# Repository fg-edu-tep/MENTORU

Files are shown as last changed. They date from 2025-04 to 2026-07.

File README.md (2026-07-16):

# MENTORU

Sistema de monitoreo biométrico distribuido basado en ESP32. Varios dispositivos vestibles (reloj, gafas, pecho, sensor GSR) miden señales fisiológicas y de movimiento, y las transmiten de forma inalámbrica por **ESP-NOW** a un receptor central que las expone como JSON vía HTTP.

Proyecto de la asignatura *Fundamentos de Electrónica* (Universidad de los Andes).

## Arquitectura

Cada dispositivo sensor transmite tramas de tamaño fijo (88 bytes) usando el protocolo propio **ESB-P** (*ESP-NOW Sensor Broadcast Protocol*, ver [`ESB-P_ESP-NOW SENSOR BROADCAST PROTOCOL DRAFT 1.pdf`](<./ESB-P_  ESP-NOW SENSOR BROADCAST PROTOCOL           DRAFT 1.pdf>)). Cada trama tiene:

```c
typedef struct __attribute__((packed)) {
  char    deviceId[16];      // identifica el dispositivo
  char    broadcastType[16]; // tipo de dato: FORM, HR, VMEDIDO, ACCEL, FLEX...
  uint8_t payload[56];       // datos específicos de cada tipo
} espMessage;
```

Un único receptor ESP32 escucha todas las tramas, agrupa por `deviceId` + `broadcastType`, y sirve el último valor de cada uno en `GET /devices` como JSON.

## Dispositivos

| Carpeta | Dispositivo | Descripción |
|---|---|---|
| [`MasterReciever/`](MasterReciever) | Receptor | Proyecto PlatformIO (ESP32-S3). SoftAP + ESP-NOW, sirve `/devices`. Incluye además un sensor "Vest" propio a bordo (MPU-6050 + flex) que se muestrea localmente. |
| [`Wk/`](Wk) | Reloj | Pantalla LCD redonda + touch (CST816S) + sensor de ritmo cardíaco MAX30102, interfaz LVGL con asistente de formulario. Transmite `FORM` y `HR`. |
| [`Arduino/GSR/`](Arduino/GSR) | Sensor GSR | Lee la respuesta galvánica de la piel por ADC y transmite `VMEDIDO`. |
| [`GSR sensor/`](GSR%20sensor) | Sensor GSR (PCB) | Diseño KiCad del PCB del sensor GSR, con archivos de fabricación (gerbers). |
| [`PCB_Gafas/`](PCB_Gafas) | Gafas | Diseño KiCad del PCB del dispositivo de gafas (acelerómetro, `ACCEL`). |
| [`PCB_Pecho/`](PCB_Pecho) | Pecho | Diseño KiCad del PCB del dispositivo de pecho (acelerómetro + flex, `ACCEL`/`FLEX`). |
| [`Fuente Fundamentos/`](<Fuente Fundamentos>) · [`PCB_Fuente/`](PCB_Fuente) | Fuente de alimentación | Diseño de la fuente/boost converter (Altium y KiCad respectivamente). |
| [`Arduino/ESP32RECEPTORA/`](Arduino/ESP32RECEPTORA) | Receptor (versión anterior) | Primera versión del receptor, solo maneja Reloj (`FORM`/`HR`) y GSR (`VMEDIDO`). Reemplazada por `MasterReciever/`. |

## Hardware / PCBs (KiCad)

`KiCad_FootPrints/` contiene las librerías de footprints y símbolos usadas por los diseños anteriores:

- `usini_kicad_sensors-main/` — librería de sensores I2C de terceros (ADXL345, BMP180, MPL3115A2, PAJ7620, SI7021, TSL2561, INA219, BH1750, BME280/680, MAX30102, MPU6050, VL53L0X, MLX90614, conector de audio TRRS).
- `XIAO_ESP32C3-main/` — símbolo/footprint del módulo Seeed XIAO ESP32C3.
- `ESP32-S3/`, `BoostConverter/`, `CostumFuse/`, `Transformer/` — footprints propios adicionales.

## Compilar y flashear

- **`MasterReciever/`** — proyecto PlatformIO, board `esp32-s3-devkitc-1`, framework Arduino. Compilar con `pio run` o desde la extensión de PlatformIO.
- **`Wk/`** (`Wk.ino`) y **`Arduino/*/`** — sketches de Arduino IDE, requieren el core de ESP32 y las librerías `lvgl`, `TFT_eSPI`, `MAX30105`/`heartRate`, `esp_now`.

## Documentación

- [`ESB-P_ESP-NOW SENSOR BROADCAST PROTOCOL DRAFT 1.pdf`](<./ESB-P_  ESP-NOW SENSOR BROADCAST PROTOCOL           DRAFT 1.pdf>) — especificación del protocolo de comunicación entre dispositivos y receptor.
- [`Informe_Final.pdf`](Informe_Final.pdf) — informe final del proyecto.

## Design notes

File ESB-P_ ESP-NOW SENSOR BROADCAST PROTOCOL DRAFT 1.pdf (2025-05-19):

ESB-P: ESP-NOW SENSOR BROADCAST PROTOCOL DRAFT 1.1 ----------------------------------------------------------------
Status : Experimental | Editors : Embedded Systems Team
Date : 2025-05-17 | Expires : 2026-05-17
0 Document Structure (Quick Guide for GPT Agents)
yaml
Copiar
Editar
§1 Introduction
§2 Conventions & Terminology
§3 Frame Format (generic, device-agnostic)
§4 Typical Frame Construction (step-by-step recipe) §5 Receiver Behaviour & /devices JSON schema §6 Project-Specific Frames
├─ 6.1 Reloj : FORM
├─ 6.2 Reloj : HR
├─ 6.3 GSR : VMEDIDO
├─ 6.4 Gafas : ACCEL
└─ 6.5 Pecho : ACCEL / FLEX
§7 Extensibility & Versioning
§8 Reference Source Code Pointers ┈┈┈┈┈┈┈┈┈┈┈┈┈┈┈┈┈┈┈┈┈┈┈┈┈┈┈┈┈┈┈┈┈

1 Introduction
ESB-P defines one fixed-length ESP-NOW frame that every ESP32-class Sensor Device broadcasts.
A single Receiver ESP32 listens, de-multiplexes by deviceId + broadcastType, and makes the latest values available via HTTP/JSON.

2 Conventions & Terminology
Term Meaning
deviceId | Null-terminated ASCII ≤ 15 chars identifying the board.
broadcastType | Null-terminated ASCII ≤ 15 chars describing the payload kind (“HR”,
“ACCEL”…).
frame Exactly 88 bytes transmitted with esp_now_send().
Sensor DeviceAny ESP32 that sends ESB-P frames.
Receiver The ESP32 that receives all ESB-P traffic and serves /devices JSON.

Channel: All nodes must share the same Wi-Fi channel (default 1).

3 Frame Format (generic)
c
Copiar

Editar
/* Total size: 88 bytes */
typedef struct __attribute__((packed)) {
char deviceId[16]; // §2
char broadcastType[16]; // §2
uint8_t payload[56]; // device-specific use
} espMessage;
Why 56 bytes? 16 + 16 + 56 = 88, which fits comfortably inside one ESP-NOW MAC payload (limit ≈ 250 B).

All devices send the same 88-byte struct – they just lay out the 56-byte payload differently.

4 Typical Frame Construction (Recipe)
Clear and identify

c
Copiar
Editar
espMessage msg = {}; | // zero-fill
strncpy(msg.deviceId, "MySensor01", 15); strncpy(msg.broadcastType, "TEMP", 15); Encode payload
Example: store a little-endian 32-bit float at byte 0.

c
Copiar
Editar
float T = 23.7f;
memcpy(&msg.payload[0], &T, sizeof(T)); // 4 bytes Send

c
Copiar
Editar
const uint8_t bc[6] = {0xFF,0xFF,0xFF,0xFF,0xFF,0xFF};
esp_now_send(bc, (uint8_t*)&msg, sizeof(msg));
5 Receiver Behaviour & JSON Schema
Mode: WIFI_AP_STA ➜ SoftAP “ESP_Receiver” (channel 1) plus ESP-NOW STA. Callback: On every frame, group by deviceId, then by broadcastType,
store the latest payload.

5.1 /devices Response
json

Copiar
Editar
{
"devices":[
{
"id":"Clock",
"FORM": { "edad":"25","altura":"170","peso":"70", ... }, "HR" : 72,
"ACCEL": { "ax":-12,"ay":34,"az":1000 }
},
{
"id":"GSR",
"VMEDIDO": 0.523
}
]
}
Rules

Every top-level object == one unique deviceId.

Keys inside are broadcastType values.

Receiver may attach timestamps or extra meta-fields in future.

6 Project-Specific Frames
6.1 Reloj → “FORM”
Field Offset Bytes Encoding | Example
edad 0 | 4 | ASCII "25"
altura 4 | 4 | ASCII "170"
peso 8 | 4 | ASCII "70"
vasos 12 | 4 | ASCII " 8"
hrs | 16 | 4 | ASCII " 7"
nivel 20 | 16 | ASCII "Moderado"
padding | 36 | 20 | zero n/a

6.2 Reloj → “HR”
less
Copiar
Editar
payload[0..3] : int32 little-endian (beats per minute) payload[4..55]: zero padding
6.3 GSR → “VMEDIDO”
less
Copiar

Editar
payload[0..3] : 32-bit float (skin voltage, volts) payload[4..55]: padding
6.4 Gafas → “ACCEL”
less
Copiar
Editar
payload[0..1] : int16 ax
payload[2..3] : int16 ay
payload[4..5] : int16 az
payload[6..55]: padding
6.5 Pecho → “ACCEL” & “FLEX”
ACCEL = same layout as 6.4.

FLEX : payload[0..1] = uint16 resistance (Ω); rest padding.

A device may broadcast multiple broadcastTypes back-to-back.

7 Extensibility & Versioning
A new sensor only needs to pick:

ini
Copiar
Editar
deviceId = "YourBoardName"
broadcastType = "NEWTYPE"
payload = your ≤56-byte layout
Receiver must add a case for "NEWTYPE" if it wants to parse it; otherwise it can store the raw 56-byte blob.

Future protocol versions may add uint8_t version as the first byte of the frame; receivers should ignore unknown versions safely.

8 Reference Source Code
Component | File | Notes
Clock (form + HR) | ClockDevice.ino | LVGL UI, periodic HR, sends "FORM" & "HR"
GSR probe | GSR.ino | Reads ADC, sends "VMEDIDO"
Gafas accel Gafas.ino | Reads MPU-6050, sends "ACCEL"
Pecho accel/flex | Pecho.ino | Two frames: "ACCEL" & "FLEX"
Receiver | ReceiverAP.ino | SoftAP+ESP-NOW, serves /devices JSON

All sketches compile under Arduino-ESP32 core ≥ 2.0.12.

End of ESB-P v1.1

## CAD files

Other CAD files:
KiCad_FootPrints/usini_kicad_sensors-main/sources/fusion360/MPL3115A2.f3d
KiCad_FootPrints/usini_kicad_sensors-main/sources/fusion360/PAJ7620.f3d
KiCad_FootPrints/usini_kicad_sensors-main/sources/fusion360/adxl345.f3d
KiCad_FootPrints/usini_kicad_sensors-main/sources/fusion360/audio_3.5mm_trrs.f3d
KiCad_FootPrints/usini_kicad_sensors-main/sources/fusion360/bmp180.f3d
KiCad_FootPrints/usini_kicad_sensors-main/sources/fusion360/module_si7021.f3d
KiCad_FootPrints/usini_kicad_sensors-main/sources/fusion360/tsl2561.f3d

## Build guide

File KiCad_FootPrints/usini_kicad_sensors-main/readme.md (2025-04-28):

Usini Sensors Kicad Schematics
----------------------
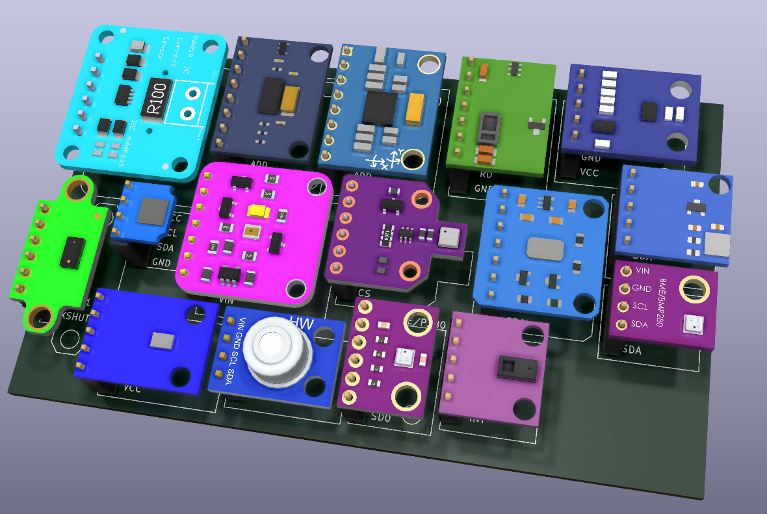
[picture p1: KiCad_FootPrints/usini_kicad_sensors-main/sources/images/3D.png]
3D models

This is my libraries of sensors breakout board for Kicad.
* All models are checked (but it is not guaranted to have no errors).
* All schematics/footprints are CC-0 public domain (some exception for 3D models)

Theses files included:
* **usini_sensors.pretty** folder with step (3D models) / kicad_mod (footprints files)
* **usini_sensors.dcm** (Schematics information)
* **usini_sensors.lib** (Schematics)

Just copy theses files in your kicad project, and add the links in the *preferences*

# Included modules
* ADXL345 Accelerometer
* INA219 Current sensor
* PAJ7620 Gesture sensor
* BH1750 Light Sensor
* BME280 Temperature / Humidity / Pressure sensor
* BME680 Temperature / Humidity / Pressure / Gas sensor
* MAX30102 Heart rate sensor
* SI7021 Temperature / Humidity Sensor
* MPL3115a2 Pressure Sensor
* TSL2561 Light sensor
* BMP180 Temperature / Pressure sensor
* MPU6050 Accelerometer sensor
* VL53L0X Distance sensor
* MLX90614 IR Temperature sensor

# How it was made
I recorded myself doing most of these.
* [Youtube Part 1](https://www.youtube.com/watch?v=2__ODQvKKTA)
* [Youtube Part 2](https://www.youtube.com/watch?v=Mm6G-MrL5dA)
* [Youtube Part 3](https://www.youtube.com/watch?v=6xK2-JJZ6IQ)

It tooks me around 8 hours to made it which would have cost 81,2€ on minimal wage, so feel free to donate at https://ko-fi.com/usini

# Schematics
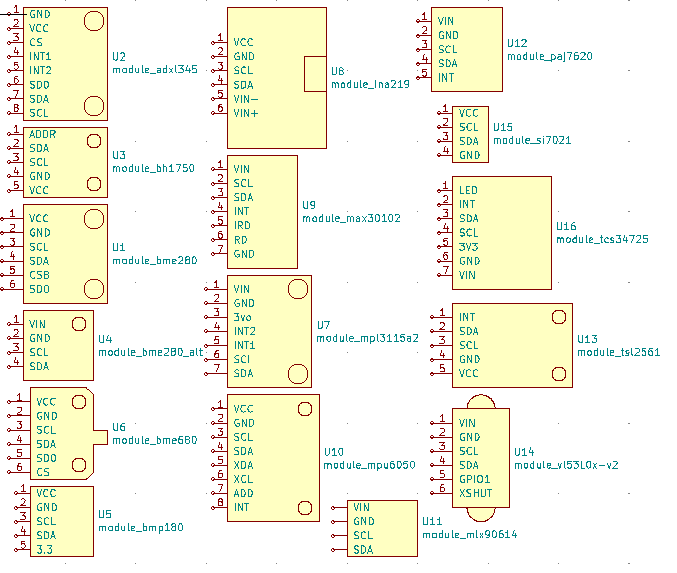
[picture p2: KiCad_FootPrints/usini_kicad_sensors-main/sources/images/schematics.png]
Schematics


# PCB (footprints)
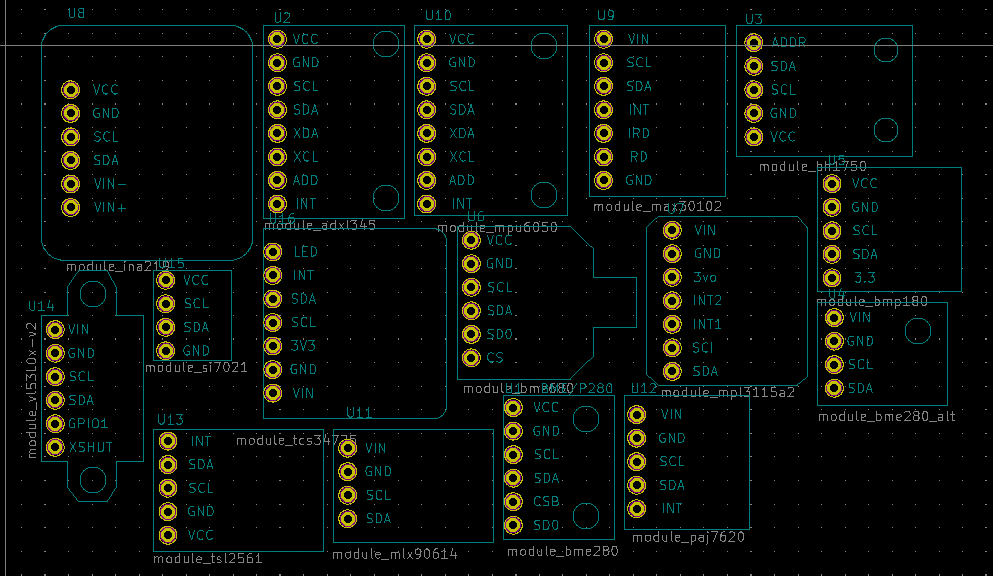
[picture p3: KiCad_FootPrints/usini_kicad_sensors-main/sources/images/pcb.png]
PCB


# 3D models
All 3D models listed here, were downloaded from grabcad, and are licenced as stated on **6.User Submissions**
```
each user of the Site -are granted- a worldwide, non-exclusive, royalty-free, fully-paid, perpetual, irrevocable, non-sublicensable, non-assignable, and non-transferable license to use.
```

* MLX90614 by Kirill Avdeev         : https://grabcad.com/library/ir-thermo-sensor-hw-691-mlx90614-1
* BME680 by Alexei Kositsin         : https://grabcad.com/library/cjmcu-680-bme680-bosch-sensor-1
* TCS34725 by Alexy Kositsin        : https://grabcad.com/library/tcs34725-rgb-sensor-module-1
* BME280 by Bernard Hess            : https://grabcad.com/library/gy-bme280-6-pin-version-1
* BME280 Alt by Marcell Stoer       : https://grabcad.com/library/gy-bme280-1
* BH1750 by Jonathan Griggs         : https://grabcad.com/library/bh1750-sensor-board-1
* INA219 by Juan J. Calle Linares   : https://grabcad.com/library/ina219-2
* MPU6050 by Nicola Cugola          : https://grabcad.com/library/mpu6050-1
* VL53l0x by Davor Granić           : https://grabcad.com/library/vl53l0x-v2-tof-sensor-1

All 3D models listed here are licenced as CC-0 Public Domain
* TSL2561 by Rémi Sarrailh          : https://grabcad.com/library/tsl2561-breakout-board-1
* PAJ7620 by Rémi Sarrailh          : https://grabcad.com/library/paj7620-breakout-board-1
* MPL3115A2 by Rémi Sarrailh        : https://grabcad.com/library/mpl3115a2-breakout-board-1
* Si7021 by Rémi Sarrailh           : https://grabcad.com/library/si7021-breakout-board-1
* BMP180 by Rémi Sarrailh           : https://grabcad.com/library/bmp180-breakout-board-2
* Audio 3.5mm TRRS by Rémi Sarrailh : https://grabcad.com/library/audio-3-5mm-trrs-1
* ADLX345 by Rémi Sarrailh          : https://grabcad.com/library/adxl345-breakout-board-1

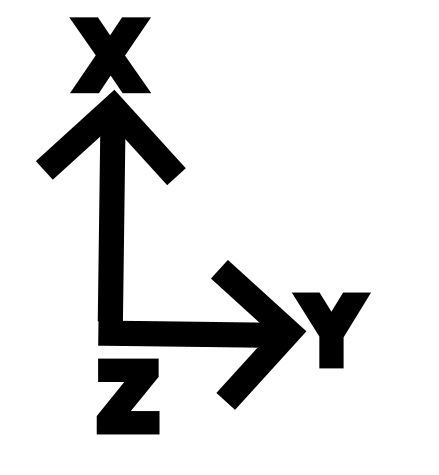
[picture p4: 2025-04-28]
KiCad_FootPrints/usini_kicad_sensors-main/sources/images/accelerometer.png

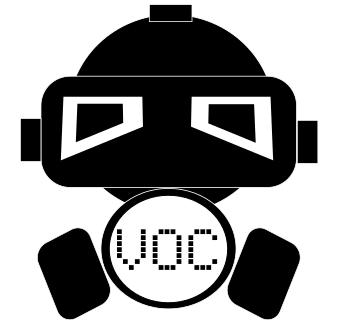
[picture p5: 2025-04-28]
KiCad_FootPrints/usini_kicad_sensors-main/sources/images/gas.png

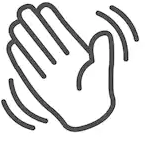
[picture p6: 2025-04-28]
KiCad_FootPrints/usini_kicad_sensors-main/sources/images/gesture_sensor.png

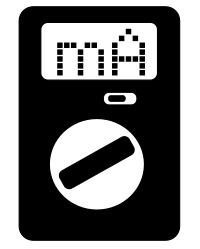
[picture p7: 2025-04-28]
KiCad_FootPrints/usini_kicad_sensors-main/sources/images/current.png

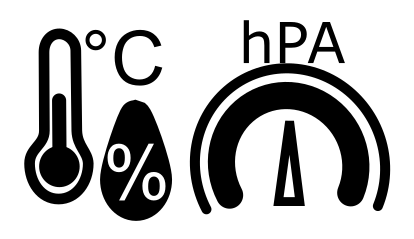
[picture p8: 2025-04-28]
KiCad_FootPrints/usini_kicad_sensors-main/sources/images/temp_hum_baro.png

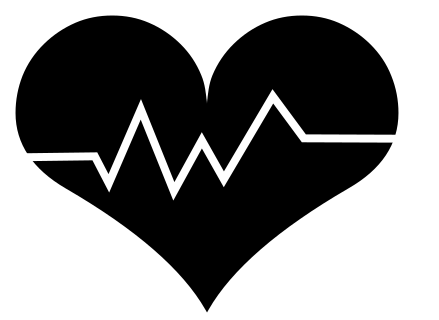
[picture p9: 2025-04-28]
KiCad_FootPrints/usini_kicad_sensors-main/sources/images/heartrate.png

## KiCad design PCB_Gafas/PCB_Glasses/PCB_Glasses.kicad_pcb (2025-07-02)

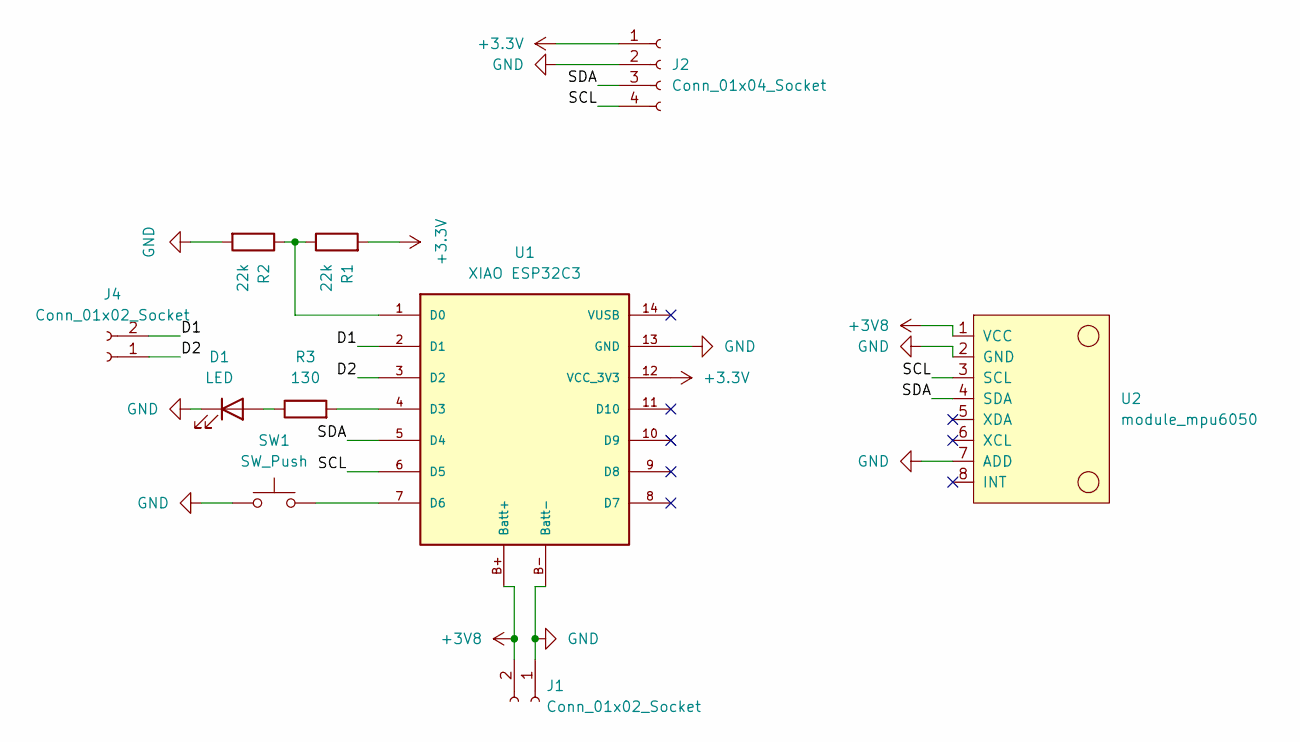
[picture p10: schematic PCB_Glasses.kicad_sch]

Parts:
D1: LED; LED_0805_2012Metric
J1, J4: Conn_01x02_Socket; JST_EH_B2B-EH-A_1x02_P2.50mm_Vertical
J2: Conn_01x04_Socket; JST_EH_B4B-EH-A_1x04_P2.50mm_Vertical
R1, R2: 22k; R_1206_3216Metric_Pad1.30x1.75mm_HandSolder
R3: 130; R_1206_3216Metric_Pad1.30x1.75mm_HandSolder
SW1: SW_Push; SW_SPST_CK_RS282G05A3
U1: XIAO ESP32C3; xiao_esp32c3
U2: module_mpu6050

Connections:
+3.3V: J2.1, R1.2, U1.12 (VCC_3V3)
+3V8: J1.2, U1.B+ (Batt+), U2.1 (VCC)
/D1: J4.2, U1.2 (D1)
/D2: J4.1, U1.3 (D2)
/SCL: J2.4, U1.6 (D5), U2.3 (SCL)
/SDA: J2.3, U1.5 (D4), U2.4 (SDA)
GND: D1.1 (K), J1.1, J2.2, R2.2, SW1.1, U1.13 (GND), U1.B- (Batt-), U2.2 (GND), U2.7 (ADD)
unnamed: D1.2 (A), R3.1
unnamed: R1.1, R2.1, U1.1 (D0)
unnamed: R3.2, U1.4 (D3)
unnamed: SW1.2, U1.7 (D6)

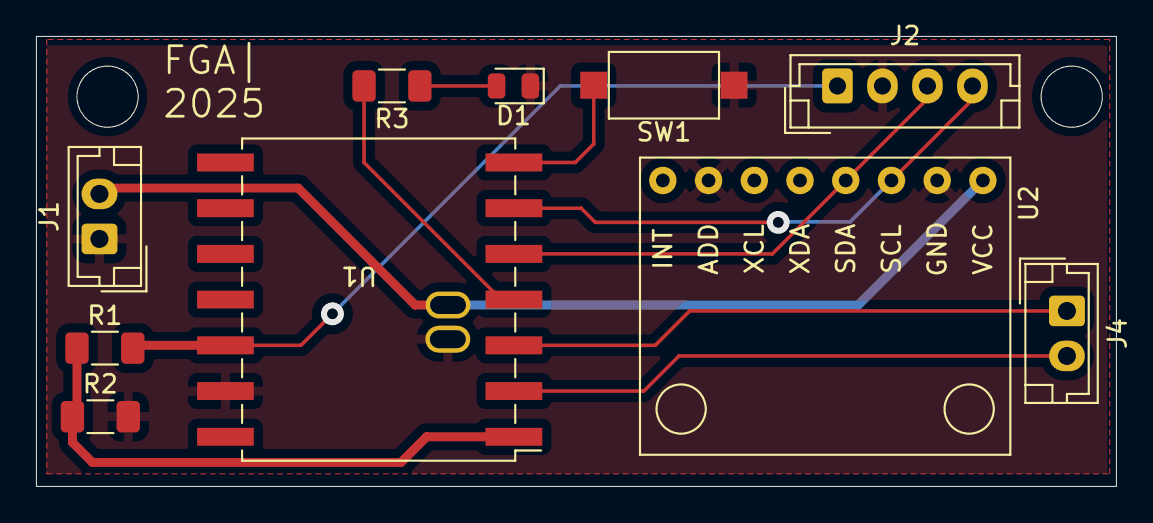
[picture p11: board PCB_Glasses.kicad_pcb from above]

Board: 2 copper layers, 60.0 x 25.0 mm, 10 parts (0 on the bottom side), 11 nets.

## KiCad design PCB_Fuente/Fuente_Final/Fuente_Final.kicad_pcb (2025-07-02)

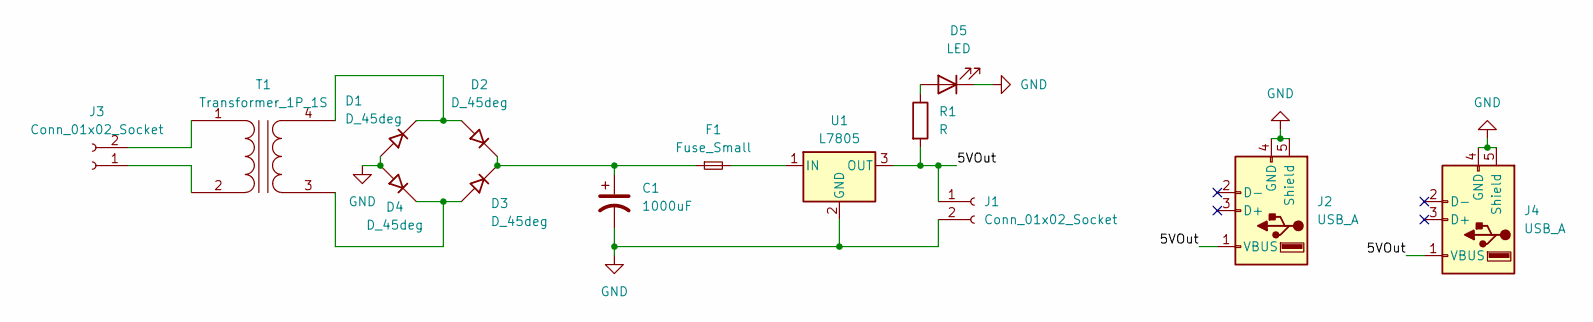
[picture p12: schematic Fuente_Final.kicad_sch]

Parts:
C1: 1000uF; CP_Radial_D10.0mm_P5.00mm
D1, D3: D_45deg; D_DO-15_P5.08mm_Vertical_AnodeUp
D2, D4: D_45deg; D_DO-15_P5.08mm_Vertical_KathodeUp
D5: LED; LED_0805_2012Metric_Pad1.15x1.40mm_HandSolder
F1: Fuse_Small; Fuse_MF-SMDF200-2_Custom
J1: Conn_01x02_Socket; JST_EH_B2B-EH-A_1x02_P2.50mm_Vertical
J2, J4: USB_A; USB_A_Receptacle_GCT_USB1046
J3: Conn_01x02_Socket; TerminalBlock_bornier-2_P5.08mm
R1: R; R_0805_2012Metric_Pad1.20x1.40mm_HandSolder
T1: Transformer_1P_1S; THT_10mm_Transformer
U1: L7805; TO-220-3_Vertical

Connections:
/5VOut: J1.1, J2.1 (VBUS), J4.1 (VBUS), R1.2, U1.3 (OUT)
GND: C1.2, D1.2 (A), D4.2 (A), D5.1 (K), J1.2, J2.4 (GND), J2.5 (Shield), J4.4 (GND), J4.5 (Shield), U1.2 (GND)
unnamed: D1.1 (K), D2.2 (A), T1.4 (SB)
unnamed: C1.1, D2.1 (K), D3.1 (K), F1.1
unnamed: D3.2 (A), D4.1 (K), T1.3 (SA)
unnamed: D5.2 (A), R1.1
unnamed: J3.1, T1.2 (AB)
unnamed: J3.2, T1.1 (AA)
unnamed: F1.2, U1.1 (IN)

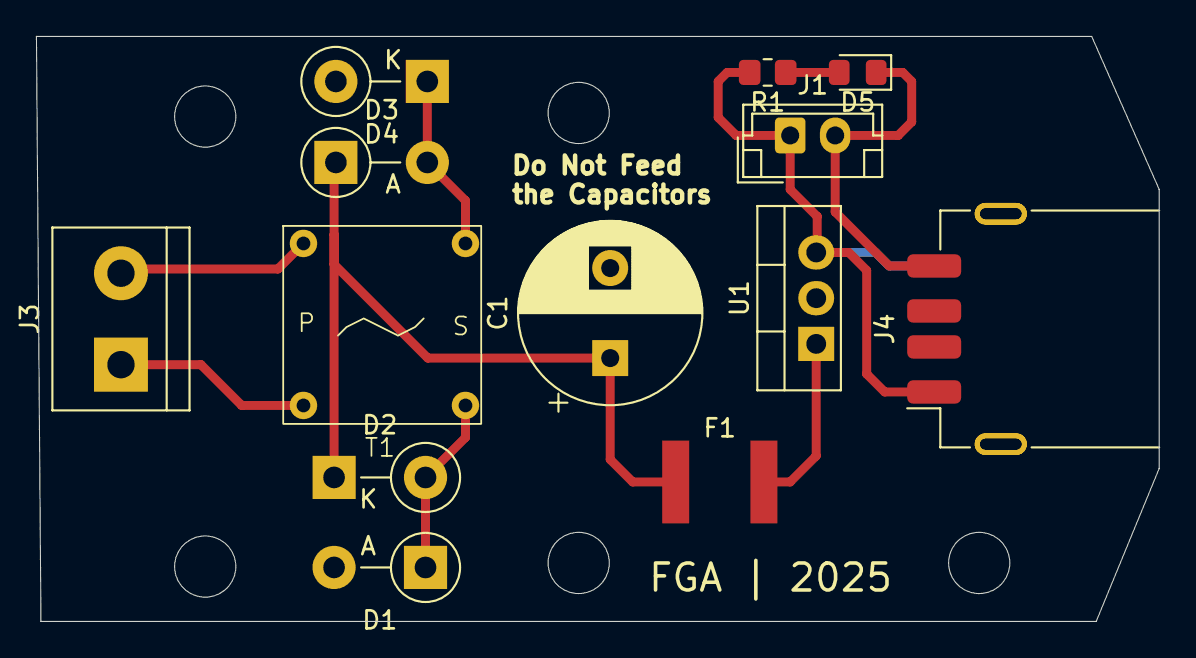
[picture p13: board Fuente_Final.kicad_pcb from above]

Board: 2 copper layers, 62.4 x 32.5 mm, 14 parts (1 on the bottom side), 9 nets.

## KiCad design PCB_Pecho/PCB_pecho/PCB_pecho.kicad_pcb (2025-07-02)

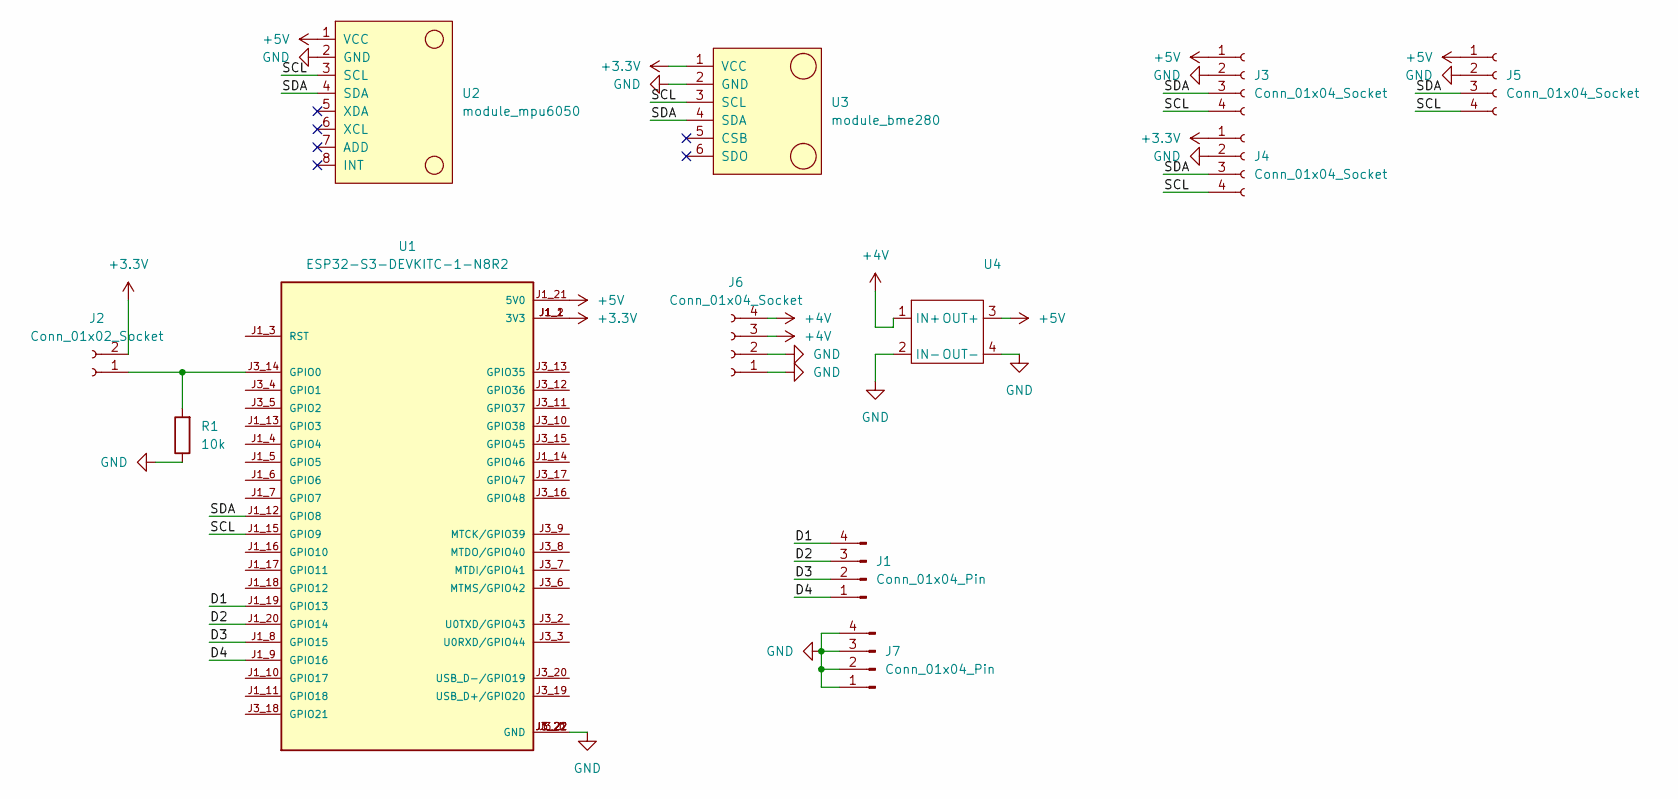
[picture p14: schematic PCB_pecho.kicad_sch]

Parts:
J1, J7: Conn_01x04_Pin; JST_EH_B4B-EH-A_1x04_P2.50mm_Vertical
J2: Conn_01x02_Socket; JST_EH_B2B-EH-A_1x02_P2.50mm_Vertical
J3, J4, J5, J6: Conn_01x04_Socket; JST_EH_B4B-EH-A_1x04_P2.50mm_Vertical
R1: 10k; R_1206_3216Metric_Pad1.30x1.75mm_HandSolder
U1: ESP32-S3-DEVKITC-1-N8R2; XCVR_ESP32-S3-DEVKITC-1-N8R2; PARTREV V1
U2: module_mpu6050
U3: module_bme280
U4: (no value)

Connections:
+3.3V: J2.2, J4.1, U1.J1_1 (3V3), U1.J1_2 (3V3), U3.1 (VCC)
+4V: J6.3, J6.4, U4.1 (IN+)
+5V: J3.1, J5.1, U1.J1_21 (5V0), U2.1 (VCC), U4.3 (OUT+)
/D1: J1.4, U1.J1_19 (GPIO13)
/D2: J1.3, U1.J1_20 (GPIO14)
/D3: J1.2, U1.J1_8 (GPIO15)
/D4: J1.1, U1.J1_9 (GPIO16)
/SCL: J3.4, J4.4, J5.4, U1.J1_15 (GPIO9), U2.3 (SCL), U3.3 (SCL)
/SDA: J3.3, J4.3, J5.3, U1.J1_12 (GPIO8), U2.4 (SDA), U3.4 (SDA)
GND: J3.2, J4.2, J5.2, J6.1, J6.2, J7.1, J7.2, J7.3, J7.4, R1.1, U1.J1_22 (GND), U1.J3_1 (GND), U1.J3_21 (GND), U1.J3_22 (GND), U2.2 (GND), U3.2 (GND), U4.2 (IN-), U4.4 (OUT-)
unnamed: J2.1, R1.2, U1.J3_14 (GPIO0)

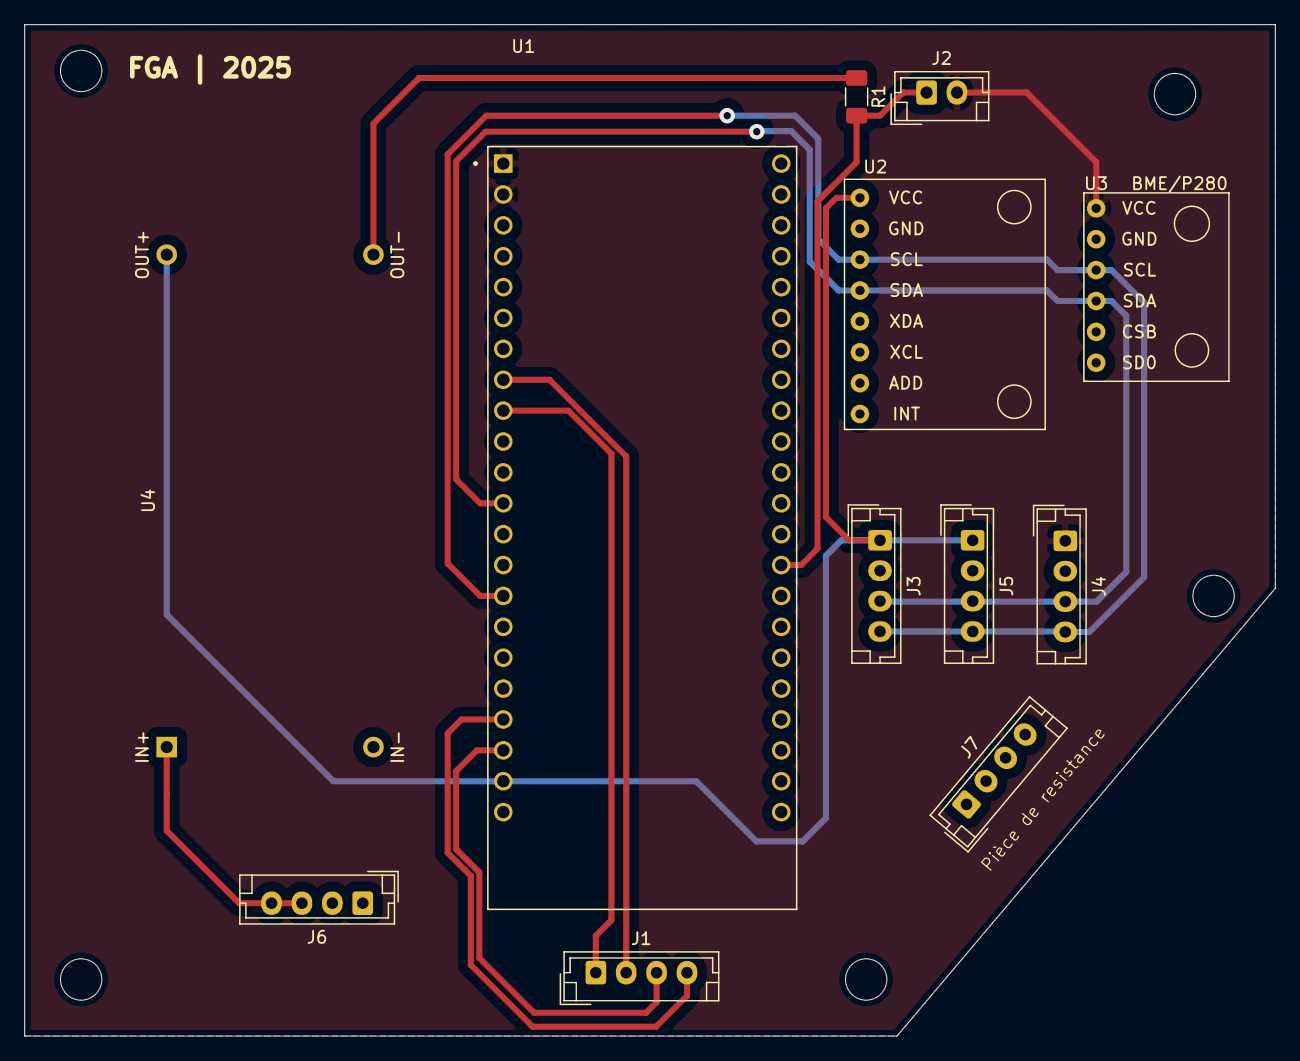
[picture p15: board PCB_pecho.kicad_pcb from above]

Board: 2 copper layers, 102.9 x 83.2 mm, 12 parts (0 on the bottom side), 11 nets.

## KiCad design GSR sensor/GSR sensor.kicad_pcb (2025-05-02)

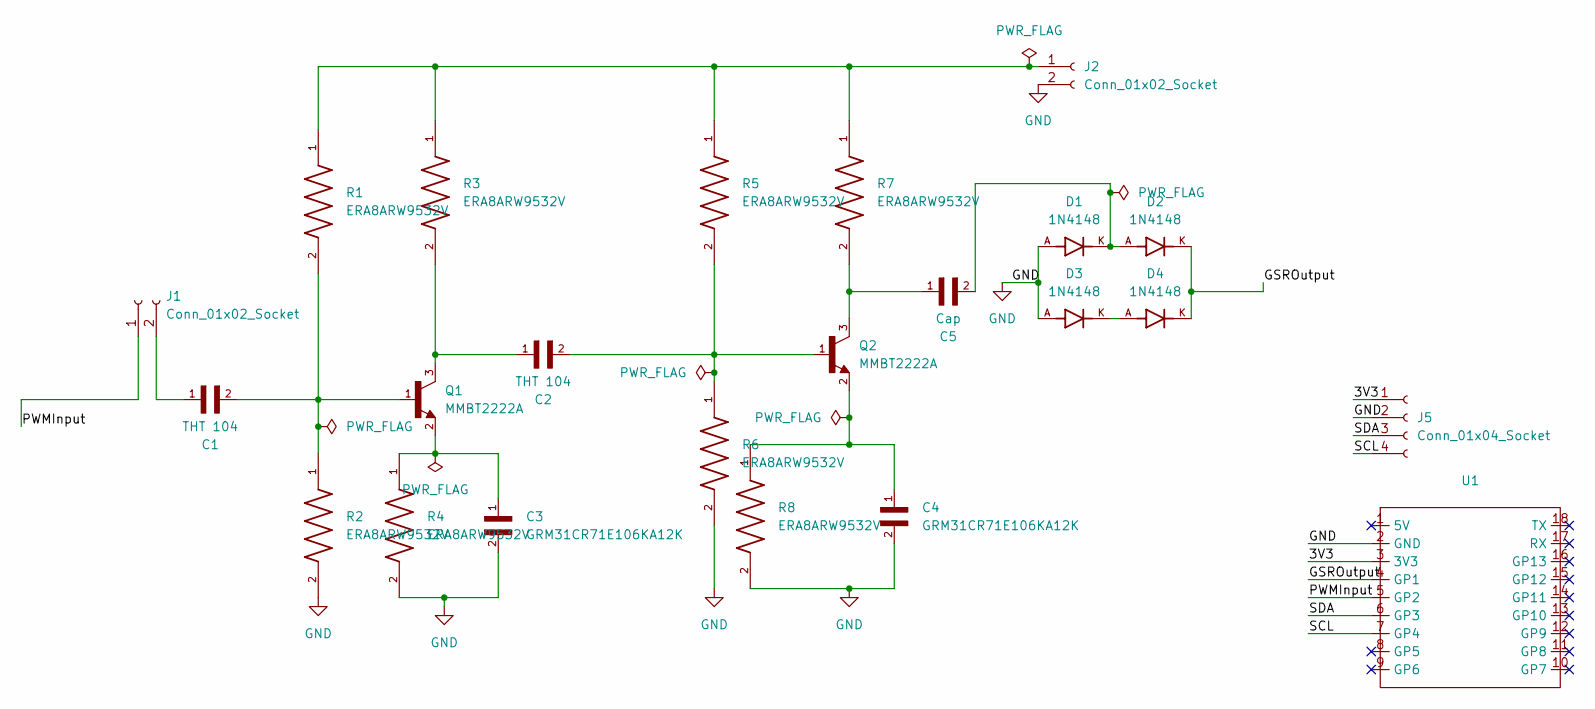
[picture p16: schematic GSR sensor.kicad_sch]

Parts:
C1, C2: THT 104; C_Radial_D5.0mm_H7.0mm_P2.00mm
C3, C4: GRM31CR71E106KA12K; CAPC3216X180N
C5: Cap; CAPC3216X180N
D1, D2, D3, D4: 1N4148; DIOAD753W49L380D172B; PARTREV 5
J1, J2: Conn_01x02_Socket; JST_EH_B2B-EH-A_1x02_P2.50mm_Vertical
J5: Conn_01x04_Socket; JST_EH_B4B-EH-A_1x04_P2.50mm_Vertical
Q1, Q2: MMBT2222A; SOT95P240X120-3N; PARTREV 2024-03-11
R1, R2, R3, R4, R5, R6, R7, R8: ERA8ARW9532V; RES_ERA8ARW9532V; PARTREV 3/1/2020
U1: ESP32-S3-XIAO

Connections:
/3V3: J5.1, U1.3 (3V3)
/GSROutput: D2.K, D4.K, U1.4 (GP1)
/PWMInput: J1.1, U1.5 (GP2)
/SCL: J5.4, U1.7 (GP4)
/SDA: J5.3, U1.6 (GP3)
GND: C3.2, C4.2, D1.A, D3.A, J2.2, J5.2, R2.2, R4.2, R6.2, R8.2, U1.2 (GND)
unnamed: C1.2, Q1.1, R1.2, R2.1
unnamed: C2.1, Q1.3, R3.2
unnamed: C2.2, Q2.1, R5.2, R6.1
unnamed: C3.1, Q1.2, R4.1
unnamed: C4.1, Q2.2, R8.1
unnamed: C5.1, Q2.3, R7.2
unnamed: C5.2, D1.K, D2.A
unnamed: D3.K, D4.A
unnamed: C1.1, J1.2
unnamed: J2.1, R1.1, R3.1, R5.1, R7.1

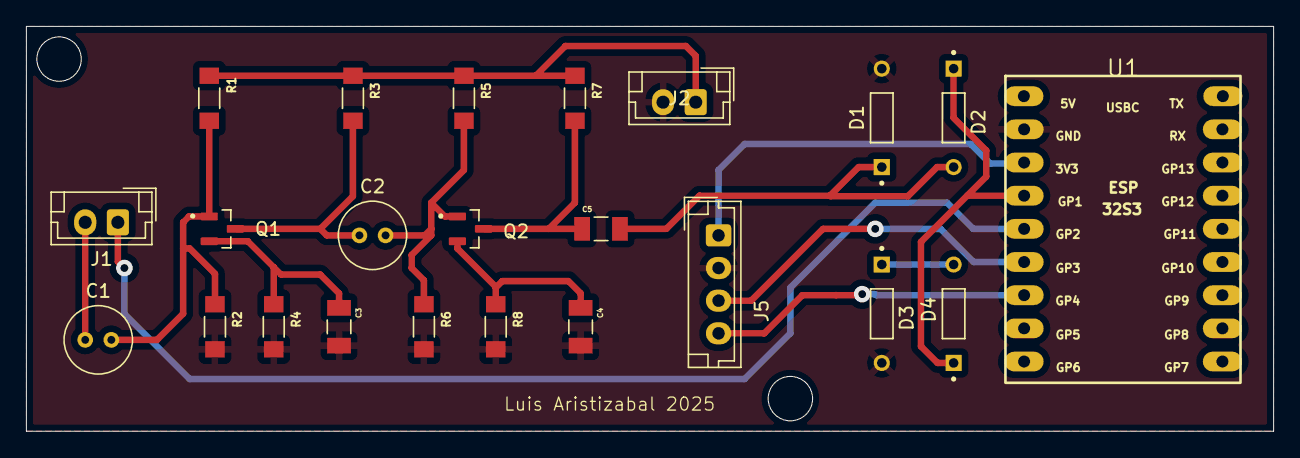
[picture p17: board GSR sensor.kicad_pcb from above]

Board: 2 copper layers, 95.5 x 31.0 mm, 23 parts (0 on the bottom side), 16 nets.

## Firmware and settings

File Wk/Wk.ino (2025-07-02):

/********************************************************************
 *  ClockDevice  —  Round LCD + MAX30102 + ESP-NOW (ESB-P) v1.1
 *
 *  • Two I²C buses
 *      – Wire   : touch CST816S (GPIO6/7/13/5)
 *      – I2C_MAX: MAX30102 HR sensor (GPIO17 SDA, 18 SCL)
 *  • Form wizard  →   IMC (BMI) screen (orange)  →  HR screen
 *  • Broadcasts
 *      – "FORM" once after Enviar
 *      – "HR"  every 5 s with **real** BPM
 ********************************************************************/
#include <Wire.h>
#include <lvgl.h>
#include <TFT_eSPI.h>
#include "CST816S.h"
#include <WiFi.h>
#include <esp_now.h>
#include "MAX30105.h"
#include "heartRate.h"

/* ───────── LVGL / HR timing ───────── */
#define LVGL_TICK_MS    2
#define HR_TX_MS        5000   // 5 s broadcast

/* ───────── Screen & buffer ───────── */
static const uint16_t SW = 240, SH = 240;
static lv_disp_draw_buf_t draw_buf;
static lv_color_t buf[SW*SH/10];

/* ───────── Hardware objects ───────── */
TFT_eSPI   tft(SW, SH);
CST816S    touch(6, 7, 13, 5);
TwoWire    I2C_MAX(1);                 // I²C1  for MAX30102
MAX30105   heart;

/* ───────── ESP-NOW peer ───────── */
const uint8_t BC_ADDR[6] = {0xFF,0xFF,0xFF,0xFF,0xFF,0xFF};

/* ───────── ESB-P frame ───────── */
typedef struct {
  char deviceId[16];
  char broadcastType[16];
  uint8_t payload[56];                 // first 4 = hr for "HR"
} espMessage;
static espMessage frame;

/* ───────── Form state ───────── */
static const char *labels[] = {
  "Edad", "Altura (cm)", "Peso (kg)",
  "# Vasos Agua", "Hrs Dormidas", "Actividad Física"
};
enum { F_EDAD, F_ALT, F_PESO, F_VASOS, F_HRS, F_NIVEL, F_BMI, F_DONE };
static int    step      = 0;           // wizard step
static lv_obj_t *roller,*lblTitle,*lblBpm,*lblAlert,*btnPrev,*btnNext,*lblBMI;

/* Stored answers (ASCII) */
char sEdad[4]="", sAlt[4]="", sPeso[4]="", sVasos[4]="",
     sHrs[4]="", sNivel[16]="";

/* HR processing */
static unsigned long lastBeatMs=0, lastHrSend=0;
static int  bpmCurrent = 0;            // latest measured

/* ───────── Helpers ───────── */
String rangeStr(int lo,int hi){
  String s; for(int v=lo;v<=hi;v++){ s+=String(v); if(v<hi)s+="\n"; }
  return s;
}
float calcBMI(){
  int h=atoi(sAlt), w=atoi(sPeso);
  if(!h) return 0;
  float hm=h/100.0;
  return w/(hm*hm);
}

/* ───────── ESP-NOW init ───────── */
void initEspNow(){
  WiFi.mode(WIFI_STA);
  esp_now_init();
  esp_now_peer_info_t p={};
  memcpy(p.peer_addr,BC_ADDR,6);
  p.channel=1; p.encrypt=false;
  esp_now_add_peer(&p);
}

/* ───────── LVGL display flush ───────── */
void flush_cb(lv_disp_drv_t *d,const lv_area_t *a,lv_color_t *c){
  uint32_t w=a->x2-a->x1+1, h=a->y2-a->y1+1;
  tft.startWrite();
  tft.setAddrWindow(a->x1,a->y1,w,h);
  tft.pushColors((uint16_t*)c,w*h,true);
  tft.endWrite();
  lv_disp_flush_ready(d);
}
void lv_tick(void*){ lv_tick_inc(LVGL_TICK_MS); }
void read_touch(lv_indev_drv_t*,lv_indev_data_t *d){
  if(!touch.available()) d->state=LV_INDEV_STATE_REL;
  else{
    d->state=LV_INDEV_STATE_PR;
    d->point.x=touch.data.x; d->point.y=touch.data.y;
  }
}

/* ───────── Wizard UI builders ───────── */
void buildForm(){
  lv_obj_t *scr=lv_scr_act(); lv_obj_clean(scr);

  lblTitle = lv_label_create(scr);
  lv_label_set_text(lblTitle, labels[step]);
  lv_obj_align(lblTitle, LV_ALIGN_TOP_MID, 0, 20);

  roller = lv_roller_create(scr);
  lv_obj_set_size(roller, 180, 50);
  lv_obj_align(roller, LV_ALIGN_CENTER, 0, 0);
  lv_roller_set_visible_row_count(roller,3);

  switch(step){
    case F_EDAD  : lv_roller_set_options(roller,rangeStr(0,120).c_str(),LV_ROLLER_MODE_NORMAL); break;
    case F_ALT   : lv_roller_set_options(roller,rangeStr(100,220).c_str(),LV_ROLLER_MODE_NORMAL); break;
    case F_PESO  : lv_roller_set_options(roller,rangeStr(30,200).c_str(),LV_ROLLER_MODE_NORMAL); break;
    case F_VASOS : lv_roller_set_options(roller,rangeStr(0,20).c_str(),LV_ROLLER_MODE_NORMAL); break;
    case F_HRS   : lv_roller_set_options(roller,rangeStr(0,24).c_str(),LV_ROLLER_MODE_NORMAL); break;
    case F_NIVEL : lv_roller_set_options(roller,"Bajo\nModerado\nAlto\nMuy Alto",LV_ROLLER_MODE_NORMAL); break;
  }

  btnPrev = lv_btn_create(scr);
  lv_obj_set_size(btnPrev,60,40);
  lv_obj_align(btnPrev, LV_ALIGN_BOTTOM_LEFT,10,-10);
  lv_label_set_text(lv_label_create(btnPrev),"<");
  lv_obj_add_event_cb(btnPrev,[](lv_event_t*,void*){ if(step>0){--step; buildForm(); } },LV_EVENT_CLICKED,nullptr);

  btnNext = lv_btn_create(scr);
  lv_obj_set_size(btnNext,80,40);
  lv_obj_align(btnNext, LV_ALIGN_BOTTOM_RIGHT,-10,-10);
  lv_label_set_text(lv_label_create(btnNext), (step==F_NIVEL?"Enviar":">"));
  lv_obj_add_event_cb(btnNext,[](lv_event_t*,void*){
        char sel[16]; lv_roller_get_selected_str(roller,sel,sizeof(sel));
        switch(step){
          case F_EDAD : strcpy(sEdad ,sel); break;
          case F_ALT  : strcpy(sAlt  ,sel); break;
          case F_PESO : strcpy(sPeso ,sel); lastBMI=calcBMI(); break;
          case F_VASOS: strcpy(sVasos,sel); break;
          case F_HRS  : strcpy(sHrs  ,sel); break;
          case F_NIVEL:strcpy(sNivel,sel); break;
        }
        if(step==F_PESO){ step=F_BMI; buildBmi(); return; }
        if(step<F_NIVEL){ ++step; buildForm(); return; }

        /* SEND FORM */
        memset(&frame,0,sizeof(frame));
        strncpy(frame.deviceId,"Clock",15);
        strncpy(frame.broadcastType,"FORM",15);
        strncpy((char*)frame.payload+0 ,sEdad ,3);
        strncpy((char*)frame.payload+4 ,sAlt  ,3);
        strncpy((char*)frame.payload+8 ,sPeso ,3);
        strncpy((char*)frame.payload+12,sVasos,3);
        strncpy((char*)frame.payload+16,sHrs  ,3);
        strncpy((char*)frame.payload+20,sNivel,15);
        esp_now_send(BC_ADDR,(uint8_t*)&frame,sizeof(frame));
        step = F_DONE;
        buildHeart();
  },LV_EVENT_CLICKED,nullptr);
}

void buildBmi(){
  lv_obj_t *scr=lv_scr_act(); lv_obj_clean(scr);
  lv_obj_set_style_bg_color(scr, lv_palette_main(LV_PALETTE_ORANGE), 0);
  lblBMI = lv_label_create(scr);
  char buf[32]; snprintf(buf,sizeof(buf),"Tu IMC es:\n%.1f", lastBMI);
  lv_label_set_text(lblBMI,buf);
  lv_obj_center(lblBMI);

  lv_obj_t *btn = lv_btn_create(scr);
  lv_obj_set_size(btn,80,40);
  lv_obj_align(btn, LV_ALIGN_BOTTOM_RIGHT,-10,-10);
  lv_label_set_text(lv_label_create(btn),">");
  lv_obj_add_event_cb(btn,[](lv_event_t*,void*){ step=F_VASOS; buildForm(); },LV_EVENT_CLICKED,nullptr);
}

void buildHeart(){
  lv_obj_t *scr=lv_scr_act(); lv_obj_clean(scr);

  lv_obj_t *c=lv_obj_create(scr);
  lv_obj_set_size(c,120,120);
  lv_obj_set_style_radius(c,LV_RADIUS_CIRCLE,0);
  lv_obj_align(c,LV_ALIGN_TOP_MID,0,10);

  lblBpm = lv_label_create(c); lv_label_set_text(lblBpm,"BPM:\n--");
  lv_obj_center(lblBpm);

  lblAlert = lv_label_create(scr);
  lv_label_set_text(lblAlert,"Alerts: None");
  lv_obj_align(lblAlert,LV_ALIGN_BOTTOM_MID,0,-10);

  btnPrev = lv_btn_create(scr);
  lv_obj_set_size(btnPrev,60,40);
  lv_obj_align(btnPrev,LV_ALIGN_BOTTOM_LEFT,10,-10);
  lv_label_set_text(lv_label_create(btnPrev),"<");
  lv_obj_add_event_cb(btnPrev,[](lv_event_t*,void*){ step=0; buildForm(); },LV_EVENT_CLICKED,nullptr);
}

/* ───────── setup ───────── */
void setup(){
  Serial.begin(115200);

  /* Display & touch */
  lv_init(); tft.begin(); tft.setRotation(0);
  touch.begin();

  lv_disp_draw_buf_init(&draw_buf,buf,NULL,SW*SH/10);
  static lv_disp_drv_t dd; lv_disp_drv_init(&dd);
  dd.hor_res=SW; dd.ver_res=SH; dd.flush_cb=flush_cb; dd.draw_buf=&draw_buf;
  lv_disp_drv_register(&dd);
  static lv_indev_drv_t id; lv_indev_drv_init(&id);
  id.type=LV_INDEV_TYPE_POINTER; id.read_cb=read_touch;
  lv_indev_drv_register(&id);
  static esp_timer_create_args_t ta={.callback=&lv_tick};
  esp_timer_handle_t tm; esp_timer_create(&ta,&tm);
  esp_timer_start_periodic(tm,LVGL_TICK_MS*1000);

  /* MAX30102 */
  I2C_MAX.begin(17,18,400000);
  if(!heart.begin(I2C_MAX)) Serial.println("MAX30102 not found!");
  heart.setup(0x1F,4,2,100,411,4096);

  initEspNow();
  buildForm();
}

/* ───────── loop ───────── */
void loop(){
  lv_timer_handler();

  /* Heart-rate sensor */
  long ir = heart.getIR();
  if( checkForBeat(ir) ){
    unsigned long now=millis();
    unsigned long dt = now-lastBeatMs; lastBeatMs=now;
    if(dt>300){
      bpmCurrent = int(60000.0/dt + 0.5);
      char b[16]; snprintf(b,sizeof(b),"BPM:\n%d",bpmCurrent);
      if(lblBpm) lv_label_set_text(lblBpm,b);
      Serial.printf("RAW IR:%ld  BPM:%d\n",ir,bpmCurrent);
    }
  }

  /* transmit BPM every HR_TX_MS */
  if( millis()-lastHrSend >= HR_TX_MS && bpmCurrent>0 && step==F_DONE ){
    memset(&frame,0,sizeof(frame));
    strncpy(frame.deviceId,"Clock",15);
    strncpy(frame.broadcastType,"HR",15);
    memcpy(frame.payload,&bpmCurrent,sizeof(int));
    esp_now_send(BC_ADDR,(uint8_t*)&frame,sizeof(frame));
    lastHrSend=millis();
  }
}

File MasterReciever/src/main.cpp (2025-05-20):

/****************************************************************
 *  ReceiverAP + On-board “Vest” Sensor  (v2, Gafas-ready)
 *  - SoftAP  : ESPP_Receiver  (channel 1, WPA2 “12345678”)
 *  - ESP-NOW : listens to all sensors (Clock, GSR, Gafas, Pecho…)
 *  - HTTP    : /devices  ⇒ JSON table
 *  - Vest    : on-board MPU-6050 @ SDA13/SCL14 + flex on GPIO16
 ****************************************************************/
#include <WiFi.h>
#include <esp_now.h>
#include <WebServer.h>
#include <Wire.h>
#include <math.h>

/* ---------- CONFIG -------------------------------------------------- */
static const char*  AP_SSID = "ESPP_Receiver";
static const char*  AP_PSK  = "12345678";
static constexpr int HTTP_PORT   = 80;
static constexpr int MAX_DEVICES = 20;

/* ---------- ESB-P frame --------------------------------------------- */
struct __attribute__((packed)) espMessage {
  char    deviceId[16];
  char    broadcastType[16];
  uint8_t payload[56];
};

/* ---------- Per-device table ---------------------------------------- */
struct Device {
  String  id;
  bool    hasForm=false;   String formJson;
  bool    hasHr  =false;   int    lastHr=0;  unsigned long hrTs=0;
  bool    hasV   =false;   float  lastV=0;                    // GSR
  bool    hasAccel=false;  int16_t ax=0,ay=0,az=0;
  bool    hasOrient=false; float  roll=0, pitch=0;            // derived
  bool    hasFlex =false;  uint16_t flexRes=0;
};
static Device devices[MAX_DEVICES];
static int    deviceCount=0;

/* ---------- HTTP server --------------------------------------------- */
WebServer server(HTTP_PORT);

/* ---------- helpers ------------------------------------------------- */
int findOrAddDevice(const char* id){
  for(int i=0;i<deviceCount;i++)
    if(devices[i].id==id) return i;
  if(deviceCount>=MAX_DEVICES) return -1;
  devices[deviceCount].id=id;
  return deviceCount++;
}

/* ---------- ESP-NOW receive callback -------------------------------- */
void onDataRecv(const uint8_t*,const uint8_t* data,int len){
  if(len!=sizeof(espMessage)) return;
  auto* m = (espMessage*)data;
  int idx = findOrAddDevice(m->deviceId);
  if(idx<0) return;
  Device &d = devices[idx];

  if(!strcmp(m->broadcastType,"FORM")){
    d.hasForm=true;
    d.formJson = String("{")+
      "\"edad\":\""+String((char*)m->payload+0 )+"\","+
      "\"altura\":\""+String((char*)m->payload+4 )+"\","+
      "\"peso\":\""+String((char*)m->payload+8 )+"\","+
      "\"vasos\":\""+String((char*)m->payload+12)+"\","+
      "\"hrs\":\""+String((char*)m->payload+16)+"\","+
      "\"nivel\":\""+String((char*)m->payload+20)+"\"}";
  }
  else if(!strcmp(m->broadcastType,"HR")){
    d.hasHr=true;
    d.lastHr=*reinterpret_cast<const int32_t*>(&m->payload[0]);
    d.hrTs = millis();
  }
  else if(!strcmp(m->broadcastType,"VMEDIDO")){
    d.hasV=true;
    d.lastV=*reinterpret_cast<const float*>(&m->payload[0]);
  }
  else if(!strcmp(m->broadcastType,"ACCEL")){
    d.hasAccel=true;
    d.ax=*reinterpret_cast<const int16_t*>(&m->payload[0]);
    d.ay=*reinterpret_cast<const int16_t*>(&m->payload[2]);
    d.az=*reinterpret_cast<const int16_t*>(&m->payload[4]);
    /* optional orientation */
    float ax=d.ax/16384.0f, ay=d.ay/16384.0f, az=d.az/16384.0f;
    d.roll  = atan2f( ay, az ) * 57.2958f;
    d.pitch = atan2f(-ax, sqrtf(ay*ay + az*az)) * 57.2958f;
    d.hasOrient = true;
  }
  else if(!strcmp(m->broadcastType,"FLEX")){
    d.hasFlex=true;
    d.flexRes=*reinterpret_cast<const uint16_t*>(&m->payload[0]);
  }
}

/* ---------- /devices ------------------------------------------------ */
String accelJson(const Device& d){
  String s="{\"ax\":"+String(d.ax)+",\"ay\":"+String(d.ay)+",\"az\":"+String(d.az)+"}";
  if(d.hasOrient){
    s.remove(s.length()-1);          // strip '}'
    s += ",\"roll\":"+String(d.roll,1)+",\"pitch\":"+String(d.pitch,1)+"}";
  }
  return s;
}
void handleDevices(){
  String j="{\"devices\":[";
  for(int i=0;i<deviceCount;i++){
    const Device& d=devices[i];
    j+="{\"id\":\""+d.id+"\"";
    if(d.hasForm)   j+=",\"FORM\":"+d.formJson;
    if(d.hasHr)     j+=",\"HR\":"+String(d.lastHr);
    if(d.hasV)      j+=",\"VMEDIDO\":"+String(d.lastV,3);
    if(d.hasAccel)  j+=",\"ACCEL\":"+accelJson(d);
    if(d.hasFlex)   j+=",\"FLEX\":"+String(d.flexRes);
    j+="}";
    if(i<deviceCount-1) j+=",";
  }
  j+="]}";
  server.send(200,"application/json",j);
}

/* ---------- On-board Vest sensor  ----------------------------------- */
#define SDA_V 13
#define SCL_V 14
#define MPU_V 0x68
#define FLEX_PIN 16
const float VREF=3.3; const int ADCMAX=4095; const float RPULL=10000;

void initVest(){
  Wire.begin(SDA_V,SCL_V);
  Wire.beginTransmission(MPU_V);
  Wire.write(0x6B); Wire.write(0); Wire.endTransmission();
  analogReadResolution(12); analogSetAttenuation(ADC_11db);
}
void sampleVest(){
  Wire.beginTransmission(MPU_V); Wire.write(0x3B);
  if(Wire.endTransmission(false)!=0) return;
  Wire.requestFrom(MPU_V,6,true);
  if(Wire.available()!=6) return;
  int16_t ax=(Wire.read()<<8)|Wire.read();
  int16_t ay=(Wire.read()<<8)|Wire.read();
  int16_t az=(Wire.read()<<8)|Wire.read();

  int raw = analogRead(FLEX_PIN);
  float v  = raw*VREF/ADCMAX;
  float r  = (v*RPULL)/(VREF-v);

  int idx=findOrAddDevice("Vest"); if(idx<0) return;
  Device &d=devices[idx];
  d.hasAccel=true; d.ax=ax; d.ay=ay; d.az=az;
  d.hasFlex =true; d.flexRes=(uint16_t)r;
}

/* ---------- Setup --------------------------------------------------- */
void setup(){
  Serial.begin(115200);
  WiFi.mode(WIFI_AP_STA);
  WiFi.softAP(AP_SSID,AP_PSK,1);
  Serial.printf("SoftAP %s  IP %s\n",AP_SSID,WiFi.softAPIP().toString().c_str());

  esp_now_init();
  esp_now_register_recv_cb(onDataRecv);
  esp_now_peer_info_t p={}; memset(p.peer_addr,0xFF,6); p.channel=1;
  esp_now_add_peer(&p);

  server.on("/devices",handleDevices); server.begin();
  initVest();
}

/* ---------- Loop ---------------------------------------------------- */
unsigned long lastVest=0;
void loop(){
  server.handleClient();
  if(millis()-lastVest>=200){ sampleVest(); lastVest=millis(); }
}

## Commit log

2025-04-28 Sch gafas
    [MPL3115A2.f3d, PAJ7620.f3d, PCB_Glasses.kicad_pcb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]
2025-04-29 Started Gafas Routing
    [PCB_Glasses.kicad_pcb]
2025-04-29 PCB Glasses Done
    [PCB_Glasses.kicad_pcb]
2025-05-02 "Muchos Avances PBBs"
    [Fuente_Final.kicad_pcb, Fuente_Final.kicad_sch, PCB_pecho.kicad_pcb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]
2025-05-02 GSR PCB
    [GSR sensor-B_Cu.gbl, GSR sensor-B_Mask.gbs, GSR sensor-B_Paste.gbp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]
